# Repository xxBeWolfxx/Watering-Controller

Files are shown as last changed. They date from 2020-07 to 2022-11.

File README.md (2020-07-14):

# Watering-Controller
Project created as a University's exam. It is based on Arduino Nano which controls two water pumps by relays.
## Watering Controller v1.0.0

**Description**:

It is a basic project which has got keypad (microswitches) and LCD to present a menu of aplication. Arduino checks values from humidity sensors and compares them to thresholds, which are saved in EEPROM. If the sensors's values are lower than thresholds's values, pumps start working. Arduino sets logical 0 or 1 on pumps's pins.

**PCB**:
PCB was created in KiCad (soon on GitHub). 

## Watering Controller v2.0.0

**Description**:

> Still in progress

*New version of my project*. I replaced a few components and added OLED(ssd1306) display and encoder. New  design has a RTC (DS1307) which improves a pump's working.

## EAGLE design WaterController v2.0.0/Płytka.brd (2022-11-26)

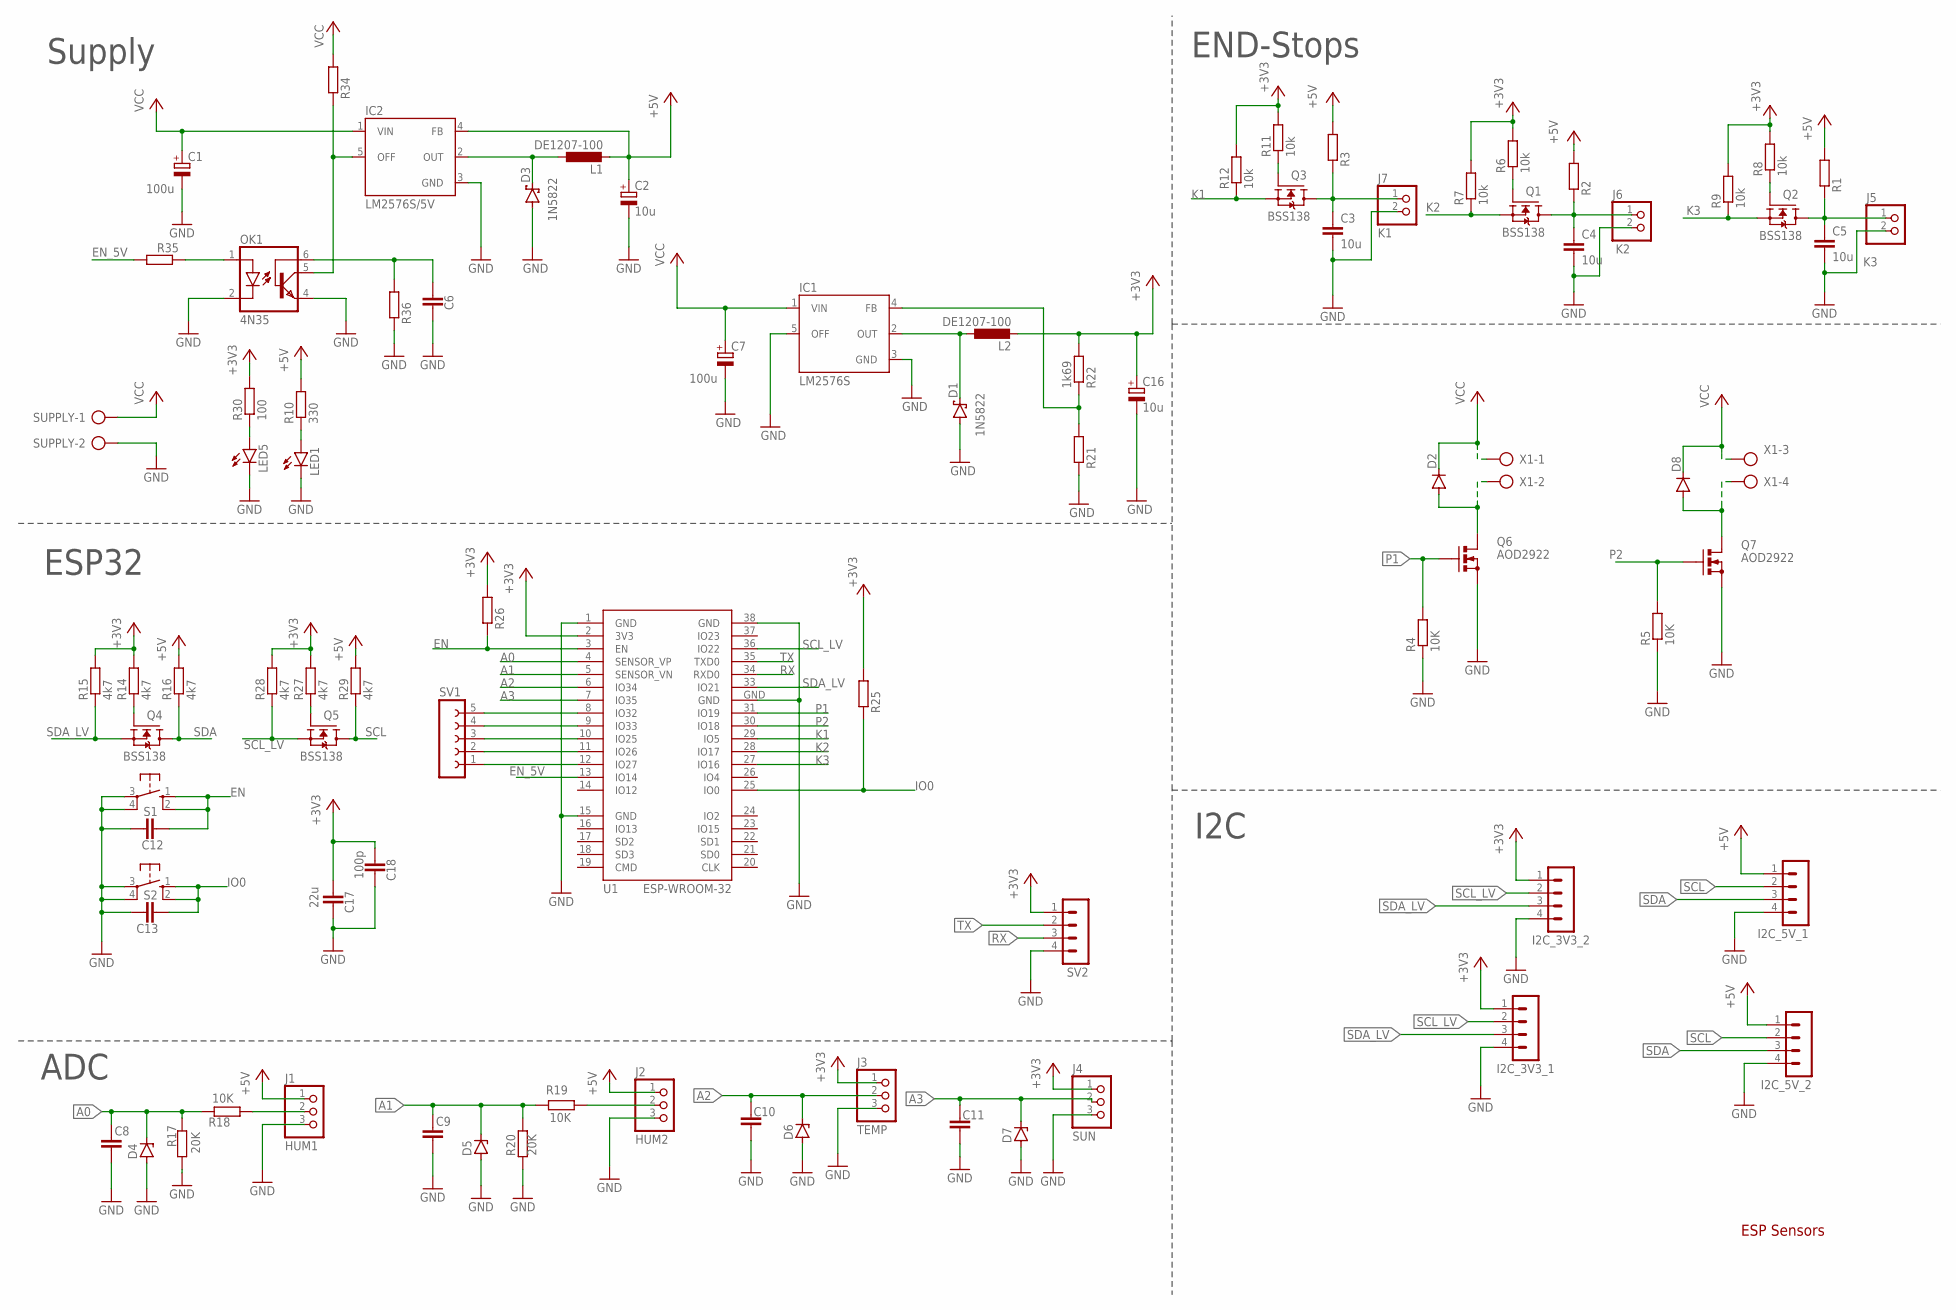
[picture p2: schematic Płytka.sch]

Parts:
C1, C7: 100u; E2,5-6
C2, C16: 10u; E3,5-8
C3, C4, C5: 10u; C0805K
C6, C8, C9, C10, C11, C12, C13: C-EUC0805K; C0805K
C17: 22u; C0805K
C18: 100p; C0805K
D1, D3: 1N5822; C4111-15
D2, D8: DIODE-DO214AC; DO214AC
D4, D5, D6, D7: ZENER-DIODESOD80C; SOD80C
I2C_3V3_1, I2C_3V3_2, I2C_5V_1, I2C_5V_2: MA04-1
IC1: LM2576S; TO263-5
IC2: LM2576S/5V; TO220-5
J1: HUM1; W_TYPE_2MM_3_N
J2: HUM2; W_TYPE_2MM_3_N
J3: TEMP; W_TYPE_2MM_3_N
J4: SUN; W_TYPE_2MM_3_N
J5: K3; W_TYPE_2MM_2_N
J6: K2; W_TYPE_2MM_2_N
J7: K1; W_TYPE_2MM_2_N
L1, L2: DE1207-100; DE1207
LED1, LED5: LEDSML0805; SML0805
OK1: 4N35; DIL06
Q1, Q2, Q3, Q4, Q5: BSS138; SOT23
Q6, Q7: AOD2922; TO252AA
R1, R2, R3, R21, R25, R26, R34, R35, R36: R-EU_R0805; R0805
R4, R5, R18, R19: 10K; R0805
R6, R7, R8, R9, R11, R12: 10k; R0805
R10: 330; R0805
R14, R15, R16, R27, R28, R29: 4k7; R0805
R17, R20: 20K; R0805
R22: 1k69; R0805
R30: 100; R0805
S1, S2: 10-XX; B3F-10XX
SUPPLY: AK500/2-H
SV1: FE05-1
SV2: MA04-1
U1: ESP-WROOM-32
X1: + P2; AK500/4

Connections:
+3V3: C16.+, C17.2, C18.2, I2C_3V3_1.1, I2C_3V3_2.1, J3.1, J4.1, L2.2, R6.2, R7.2, R8.2, R9.2, R11.2, R12.2, R14.2, R15.2, R22.2, R25.2, R26.2, R27.2, R28.2, R30.2, SV2.1, U1.2 (3V3)
+5V: C2.+, I2C_5V_1.1, I2C_5V_2.1, IC2.4 (FB), J1.1, J2.1, L1.2, R1.2, R2.2, R3.2, R10.2, R16.2, R29.2
A0: C8.1, D4.C, R17.2, R18.2, U1.4 (SENSOR_VP)
A1: C9.1, D5.C, R19.2, R20.1, U1.5 (SENSOR_VN)
A2: C10.1, D6.C, J3.2, U1.6 (IO34)
A3: C11.1, D7.C, J4.2, U1.7 (IO35)
EN: C12.2, R26.1, S1.1 (S), S1.2 (S1), U1.3 (EN)
EN_5V: R35.2, U1.13 (IO14)
GND: C1.-, C2.-, C3.2, C4.2, C5.2, C6.1, C7.-, C8.2, C9.2, C10.2, C11.2, C12.1, C13.1, C16.-, C17.1, C18.1, D1.A, D3.A, D4.A, D5.A, D6.A, D7.A, I2C_3V3_1.4, I2C_3V3_2.4, I2C_5V_1.4, I2C_5V_2.4, IC1.3 (GND), IC1.5 (OFF), IC2.3 (GND), J1.3, J2.3, J3.3, J4.3, J5.2, J6.2, J7.2, LED1.C, LED5.C, OK1.2 (C), OK1.4 (EMI), Q6.2 (S), Q7.2 (S), R4.1, R5.1, R17.1, R20.2, R21.1, R36.1, S1.3, S1.4 (P1), S2.3, S2.4 (P1), SUPPLY.2, SV2.4, U1.1 (GND), U1.15 (GND), U1.38 (GND), U1.GND
IO0: C13.2, R25.1, S2.1 (S), S2.2 (S1), U1.25 (IO0)
K1: Q3.2 (S), R12.1, U1.29 (IO5)
K2: Q1.2 (S), R7.1, U1.28 (IO17)
K3: Q2.2 (S), R9.1, U1.27 (IO16)
unnamed: C5.1, J5.1, Q2.3 (D), R1.1
unnamed: C4.1, J6.1, Q1.3 (D), R2.1
unnamed: LED1.A, R10.1
unnamed: Q4.1 (G), R14.1
unnamed: C3.1, J7.1, Q3.3 (D), R3.1
unnamed: D2.A, Q6.3 (D), X1.2
unnamed: D8.A, Q7.3 (D), X1.4
unnamed: Q5.1 (G), R27.1
unnamed: J1.2, R18.1
unnamed: SV1.5, U1.8 (IO32)
unnamed: Q1.1 (G), R6.1
unnamed: SV1.4, U1.9 (IO33)
unnamed: Q2.1 (G), R8.1
unnamed: SV1.3, U1.10 (IO25)
unnamed: Q3.1 (G), R11.1
unnamed: SV1.2, U1.11 (IO26)
unnamed: J2.2, R19.1
unnamed: D3.C, IC2.2 (OUT), L1.1
unnamed: D1.C, IC1.2 (OUT), L2.1
unnamed: SV1.1, U1.12 (IO27)
unnamed: LED5.A, R30.1
unnamed: IC2.5 (OFF), OK1.5 (COL), R34.1
unnamed: OK1.1 (A), R35.1
unnamed: C6.2, OK1.6 (BAS), R36.2
unnamed: IC1.4 (FB), R21.2, R22.1
P1: Q6.1 (G), R4.2, U1.31 (IO19)
P2: Q7.1 (G), R5.2, U1.30 (IO18)
RX: SV2.3, U1.34 (RXD0)
SCL: I2C_5V_1.2, I2C_5V_2.2, Q5.3 (D), R29.1
SCL_LV: I2C_3V3_1.2, I2C_3V3_2.2, Q5.2 (S), R28.1, U1.36 (IO22)
SDA: I2C_5V_1.3, I2C_5V_2.3, Q4.3 (D), R16.1
SDA_LV: I2C_3V3_1.3, I2C_3V3_2.3, Q4.2 (S), R15.1, U1.33 (IO21)
TX: SV2.2, U1.35 (TXD0)
VCC: C1.+, C7.+, D2.C, D8.C, IC1.1 (VIN), IC2.1 (VIN), R34.2, SUPPLY.1, X1.1, X1.3

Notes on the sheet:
Supply
ESP32
ADC
I2C
END-Stops
ESP Sensors

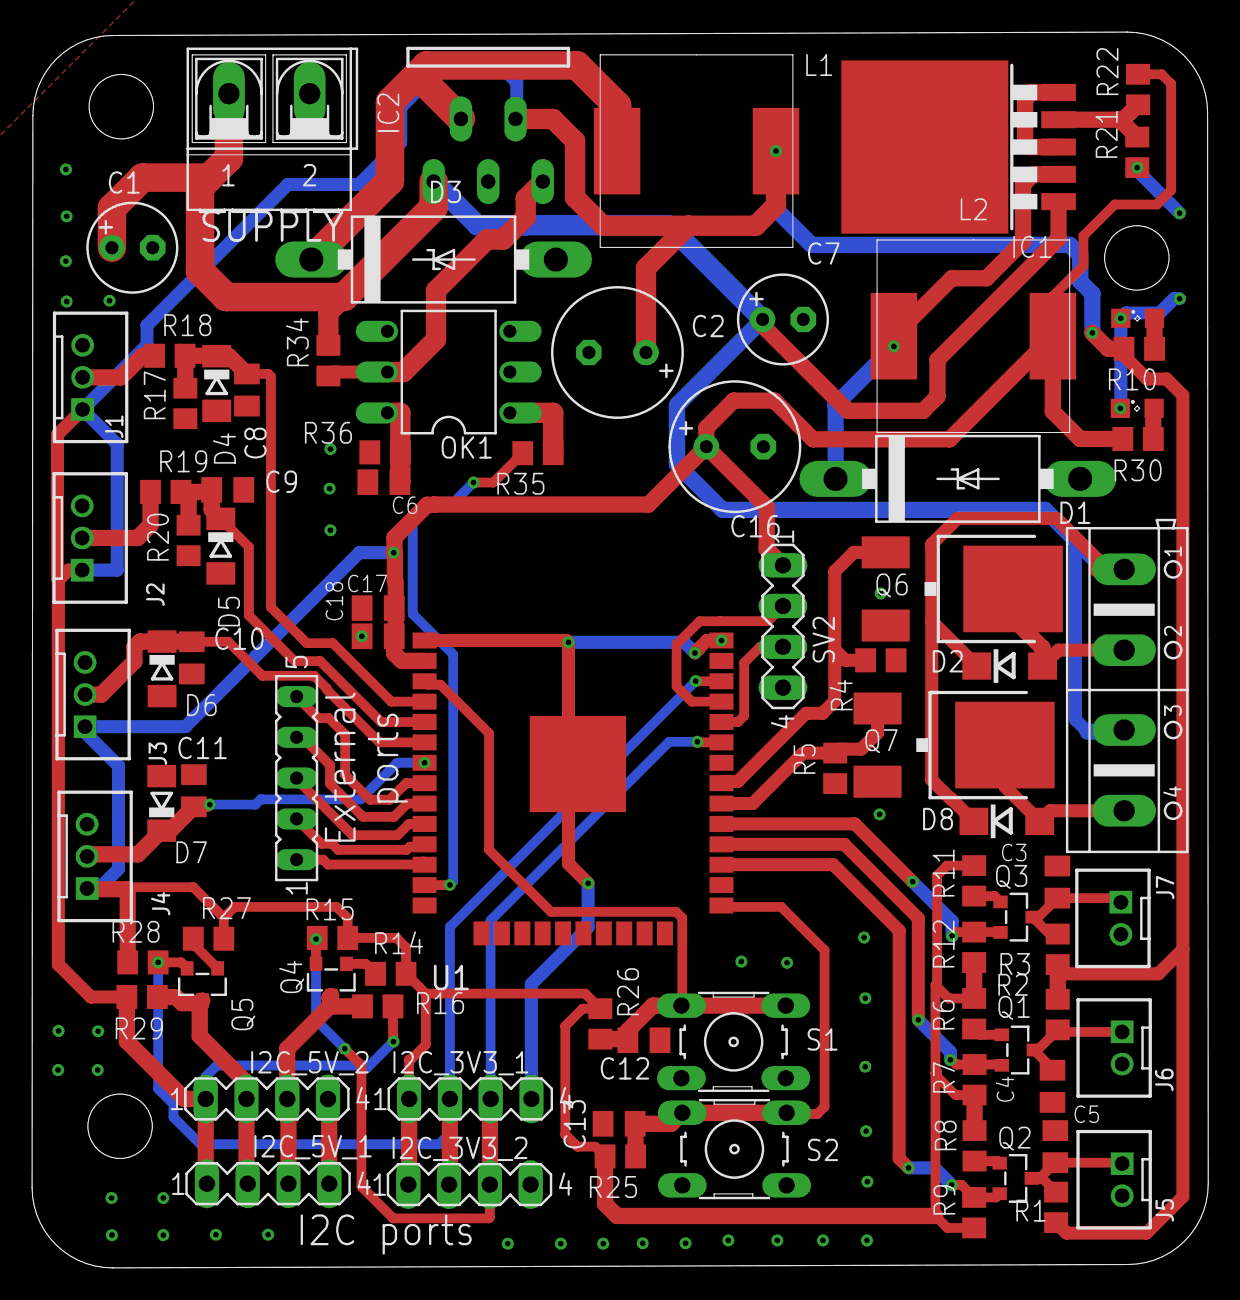
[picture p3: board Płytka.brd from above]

Board: 2 copper layers, 73.3 x 77.0 mm, 86 parts (0 on the bottom side), 47 nets.

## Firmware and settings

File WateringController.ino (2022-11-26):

<<<<<<< HEAD
//v2.0.0

#include <EEPROM.h>
#include <Adafruit_GFX.h>
#include <Adafruit_SSD1306.h>
#include <SPI.h>
#include <Wire.h>

#define SCREEN_WIDTH 124 // OLED display width, in pixels
#define SCREEN_HEIGHT 28 // OLED display height, in pixels

#define EEPROMthreshold1 0
#define EEPROMthreshold2 1
#define EEPROMtemperature 2

#define sensors1 A0
#define sensors2 A1
#define sensors3 A2
#define TemperatureSensor A3

#define PUMP1 13 //YOU MUST CHECK if this is correct
#define PUMP2 11

//**************************Define special function**********************************
void SensoreRead(); //reading values from sensors
void WaterPump();   //turn on or off diods and pumps

//**************************Variables********************************
String words[7][2] =
    {
        {"Watering", "Controller v2.0.0"},
        {"Plant:", "Humidity:"},
        {"Temperature:", "Period:"},
        {"1.Plant", "2.Plant"},
        {"2.Changing", "Value:"},
        {"     SAVED!     ", "       Return       "},
        {"     >     ", "ESC"}

};                           //declare all scenes
Adafruit_SSD1306 display(9); //

int threshold1 = 0; //set threshold for each plant
int threshold2 = 0;
int Thresholdtemperature = 0;
int temphold1; //temporary value of thresholds, which disappear after turnig off
int temphold2;

int sensorTemperature = 0;
int sensorHUM1 = 0; //value of humidity sensor
int sensorHUM2 = 0;
int sensorBright = 0;

int tabValue[10][4];
int screenOLED = 0;                                    //which scene is showing now
int workingPeriod[] = {2, 4, 5, 10, 30, 60, 120};      //how long the pump have to works
int workingIntensity[] = {5, 10, 20, 40, 50, 80, 100}; //how many energy need to

//*******************************counters***********************************

int counter = 0; //counters which will count every period of every executing
int counterPomp1 = 0;
int counterPomp2 = 0;

void setup()
{
    display.begin(SSD1306_SWITCHCAPVCC, 0x3C);
    display.clearDisplay();
    display.setTextSize(1);
    display.setTextColor(WHITE);

    threshold1 = EEPROM.read(EEPROMthreshold1); //read last value of threshold
    threshold2 = EEPROM.read(EEPROMthreshold2);
    Thresholdtemperature = EEPROM.read(EEPROMtemperature);

    temperature = Thresholdtemperature;
    temphold1 = threshold1;
    temphold2 = threshold2;

    DisplayOLED(screenOLED++); //show first scene on LCD

    sensorHUM1 = map(analogRead(sensors1), 1024, 0, 0, 100);
    sensorHUM2 = map(analogRead(sensors2), 1024, 0, 0, 100);
    sensorTemperature = map(analogRead(TemperatureSensor), 1024, 0, 0, 100);
    sensorBright = map(analogRead(sensors3), 1024, 0, 0, 100);
=======

void setup()
{
    int a = 3 + 5;
>>>>>>> 2357f7201e44869a9777a43edf4bb0054e2fd7d8
}

void loop()
{
<<<<<<< HEAD

    SensoreRead();
}

void SensoreRead() //add array to make avarage value of sensores
{
    tabValue[counter][0] = map(analogRead(sensors1), 1024, 0, 0, 100);
    tabValue[counter][1] = map(analogRead(sensors2), 1024, 0, 0, 100);
    tabValue[counter][2] = map(analogRead(sensors3), 1024, 0, 0, 100);
    tabValue[counter][3] = map(analogRead(TemperatureSensor), 1024, 0, 0, 100);
    if (counter == 9)
    {
        sensorBright = 0;
        sensorHUM1 = 0;
        sensorHUM2 = 0;
        sensorTemperature = 0;

        for (int i = 0; i < 10; i++)
        {
            sensorHUM1 = sensorHUM1 + tabValue[i][0];
            sensorHUM2 = sensorHUM2 + tabValue[i][1];
            sensorBright = sensorBright + tabValue[i][2];
            sensorTemperature = sensorTemperature + tabValue[i][3];
        }
        counter = 0;
        sensorHUM1 = sensorHUM1 / 10;
        sensorHUM2 = sensorHUM2 / 10;
        sensorTemperature = sensorTemperature / 10;

        return;
    }

    counter++;

    return;
}

void DisplayOLED(int screenOLED)
{
    if (screenOLED == 0)
    {
        display.setCursor(0, 0);
        display.println(words[screenOLED][screenOLED]);
        display.setCursor(0, 8);
        display.println(words[screenOLED][screenOLED + 1]);
        display.display();
    }
    if (screenOLED == 1)
    {
        display.setCursor(0, 0);
        display.print(words[screenOLED][screenOLED]);
        display.setCursor(30, 0);
        display.print(threshold1);
        display.setCursor(0, 8);
        display.println(words[screenOLED][screenOLED + 1]);
        display.setCursor(30, 0);
        display.display();
    }

    delay(2000);
}

void WaterPump(int temperature, int Sensore1, int Sensore2)
{
=======
>>>>>>> 2357f7201e44869a9777a43edf4bb0054e2fd7d8
}

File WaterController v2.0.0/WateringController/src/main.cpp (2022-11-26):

#include "PIDcontroller.h"
#include "WiFiClientSecure.h"
#include "Flowerprofile.hpp"
#include <Arduino.h>
#include <ArduinoJson.h>
#include <DallasTemperature.h>
#include <EEPROM.h>
#include <WebSocketsClient.h>
#include <WiFi.h>
#include <string.h>

#define addressID 1
#define addressScaler 2
#define baudRate 9600
#define serverIP "192.168.0.250"
#define port 80
#define reconnectInterval 5000
#define ONE_WIRE_BUS 32
#define sizeArrayTemperatures 10
#define humidityMeasure 12

//Define variables

float espID = 0;
float espRemoteID = 0;

// PIDcontroller pidController;

const char *ssid = "2.4G_echostar_5c82";
const char *password = "00035022";

OneWire oneWire(ONE_WIRE_BUS);
DallasTemperature sensorTemperature(&oneWire);

WiFiClient client;
StaticJsonDocument<200> document;
WebSocketsClient webSocket;

//END Define variables

//Define functions

void okMessage(String logTrigger, String info) {
    Serial.println("[OK] + [" + logTrigger + "] " + info);
}

void infoMessage(String logTrigger, String info) {
    Serial.println("[MESSAGE] + [" + logTrigger + "] " + info);
}

void errorMessage(String logTrigger, String info) {
    Serial.println("[ERROR] + [" + logTrigger + "] " + info);
}

bool validID(int ID) {
    espID = EEPROM.read(addressID);
    espID = espID * EEPROM.read(addressScaler);

    if (espID == ID) {
        okMessage("ID VALIDATION", "ID OKAY");
        return true;
    }

    errorMessage("ID VALIDATION", "ID WRONG");

    return false;
}

float readTemnperature() {
    sensorTemperature.requestTemperatures();
    return sensorTemperature.getTempCByIndex(0);
}

void sendDataToServer(float temperature, int humidity) {
    document["ID"] = espID;
    document["temperature"] = temperature;
    document["humidity1"] = humidity;
}

void webSocketEvent(WStype_t type, uint8_t *payload, size_t length) {

    DeserializationError error = deserializeJson(document, payload);
    if (error) {
        errorMessage("Error websocket event", error.c_str());
    }
    webSocket.sendTXT(password);
}

//END Define functions

void setup() {

    Serial.begin(baudRate);
    WiFi.begin(ssid, password);
    okMessage("SETUP", "I AM RUNING");

    pinMode(humidityMeasure, INPUT);

    while (WiFi.status() != WL_CONNECTED) {
        infoMessage("SETUP", "Waiting...");
        delay(500);
    }
    okMessage("SETUP", "WIFI WORKS");

    //websocket
    webSocket.begin(serverIP, port, "/");
    webSocket.onEvent(webSocketEvent);
    webSocket.setReconnectInterval(reconnectInterval);
    okMessage("SETUP", "WebSocket WORKS");

}

void loop() {

    int hum1 = map(analogRead(humidityMeasure), 0, 255, 0, 100);
    int temperature = readTemnperature();

    sendDataToServer(temperature, hum1);
    webSocket.loop();

    // put your main code here, to run repeatedly:
}

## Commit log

2020-01-06 Add menu, reading sensors etc.
2020-01-10 Assembly the Arduino to pcb board
2020-01-16 Change value of sensors
2020-01-19 Improve SensoreRead function, adding a average of readings
2020-04-29 Add Eagle project of PCB
    [Płytka.sch]
2020-04-29 Add Eagle project
    [Płytka.sch]
2020-06-08 End schematic in eagle
    [Płytka.sch]
2020-06-08 Add PCB
    [Płytka.brd]
2020-06-13 Add new items in PCB
    [Płytka.brd, Płytka.sch]
2020-06-15 Change reset pin of OLED
2020-06-19 Add new sensor
2020-06-26 Change name of sensors
2021-08-24 Add new board from another project
    [Płytka.brd, Płytka.sch]
2021-08-25 Create new board
    [Płytka.brd, Płytka.sch]
2021-09-12 improve board schematic
    [Płytka.brd, Płytka.sch]
2021-09-14 correct mistakes in board
    [Płytka.brd]
2021-09-24 Add new methods to PID controller

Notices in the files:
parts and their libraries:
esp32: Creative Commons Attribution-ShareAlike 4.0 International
